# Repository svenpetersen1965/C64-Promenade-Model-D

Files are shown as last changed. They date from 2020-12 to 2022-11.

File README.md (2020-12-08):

# C64-Promenade-Model-D
This is a remake of an  EPROM programmer, originally created by Jason-Ranheim. The project was made in co-operation with <a href="http://c64os.com">C64OS/Greg</a>.

I did the layout, Greg provided the information, has built the prototye and performed the testing (many but not all EPROM Types, that are listed in the <a href="https://github.com/svenpetersen1965/C64-Promenade-Model-D/blob/main/Software/PromenadeC1Man.pdf">manual</a>. A prototype for me was provided by Greg.

So, here are the project files, which I have created, "as is".

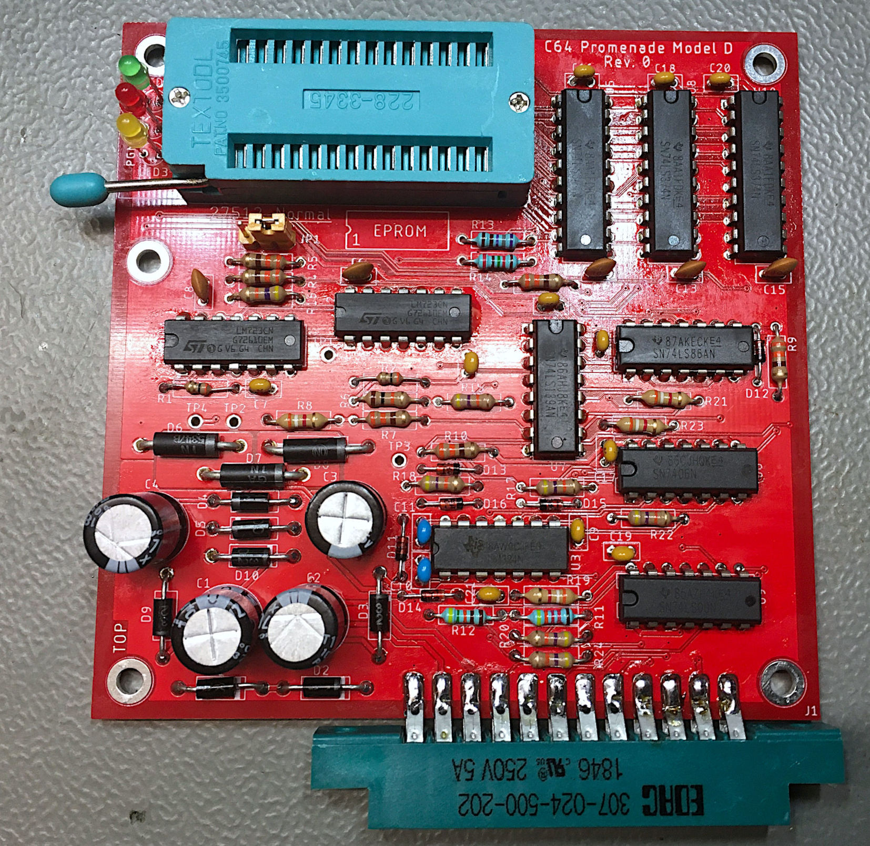
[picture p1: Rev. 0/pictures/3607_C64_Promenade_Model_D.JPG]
Promenade Model D


Since I did not test the prototype in depth, I am not able to provide support for this project.

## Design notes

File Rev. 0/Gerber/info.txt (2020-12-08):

        
       Board: C64_Promenade Model D
       Rev.:  0
  
       Files:
       ======
  
       All Gerber files are generated in extended gerber format (RS274X)
       *.TOP        : Film top copper
       *.BOT        :  -"- bottom copper
       *.STC        :  -"- top soldermask 
       *.STS        :  -"- bottom soldermask
       *.PLC        :  -"- silk screen top
       *.DK         : Drills plated Through (Excellon)
       *.NDK        : Drills not plated Through (Excellon)
       *.OUT        : Board outline

       Board Size:
       ===========
       Length     :   100.0 mm
       Width      :   100.0 mm
       Thickness  :   1.6 mm
       Material   :   FR 4
       Copper     :   35 um
       Surface    :   HASL
       
       Remarks:
       ========
       Width    >= 6 mil
       Distance >= 6 mil
       Drill    >= 0.35 mm

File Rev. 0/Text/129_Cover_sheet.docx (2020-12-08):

Project Documentation

C64 Promenade Model D

Project number: 129

Revision: 0

Date: 20.07.2019

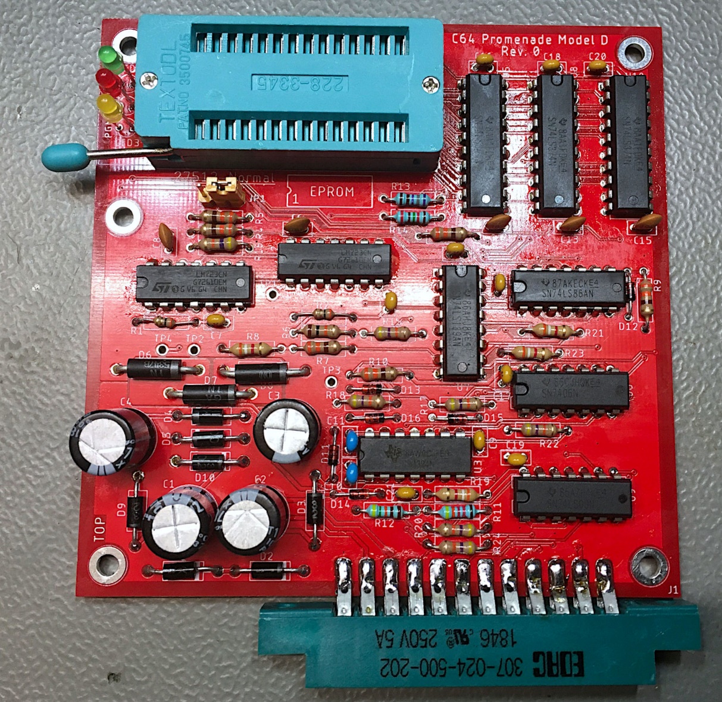
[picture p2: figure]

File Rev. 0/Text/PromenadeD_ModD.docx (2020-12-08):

C64 Promenade Model D Rev. 0

Module Description

The Promenade Model D is an EPROM programmer for the Commodore C64. The Model C is originally created by Jason-Ranheim in the 1980s. Model D is a remake of it, the layout and geometry is changed, though. The blocking of the tape port is fixed. Further, some 100n bypass capacitors were added.

This project was executed in cooperation with Greg Nacu (c64os.com). He asked me for making a layout for it. Greg has built and tested it, AFAIK with many but not all EPROM types listed.

For the documentation, please consult this website: http://c64os.com/post/promenadec1

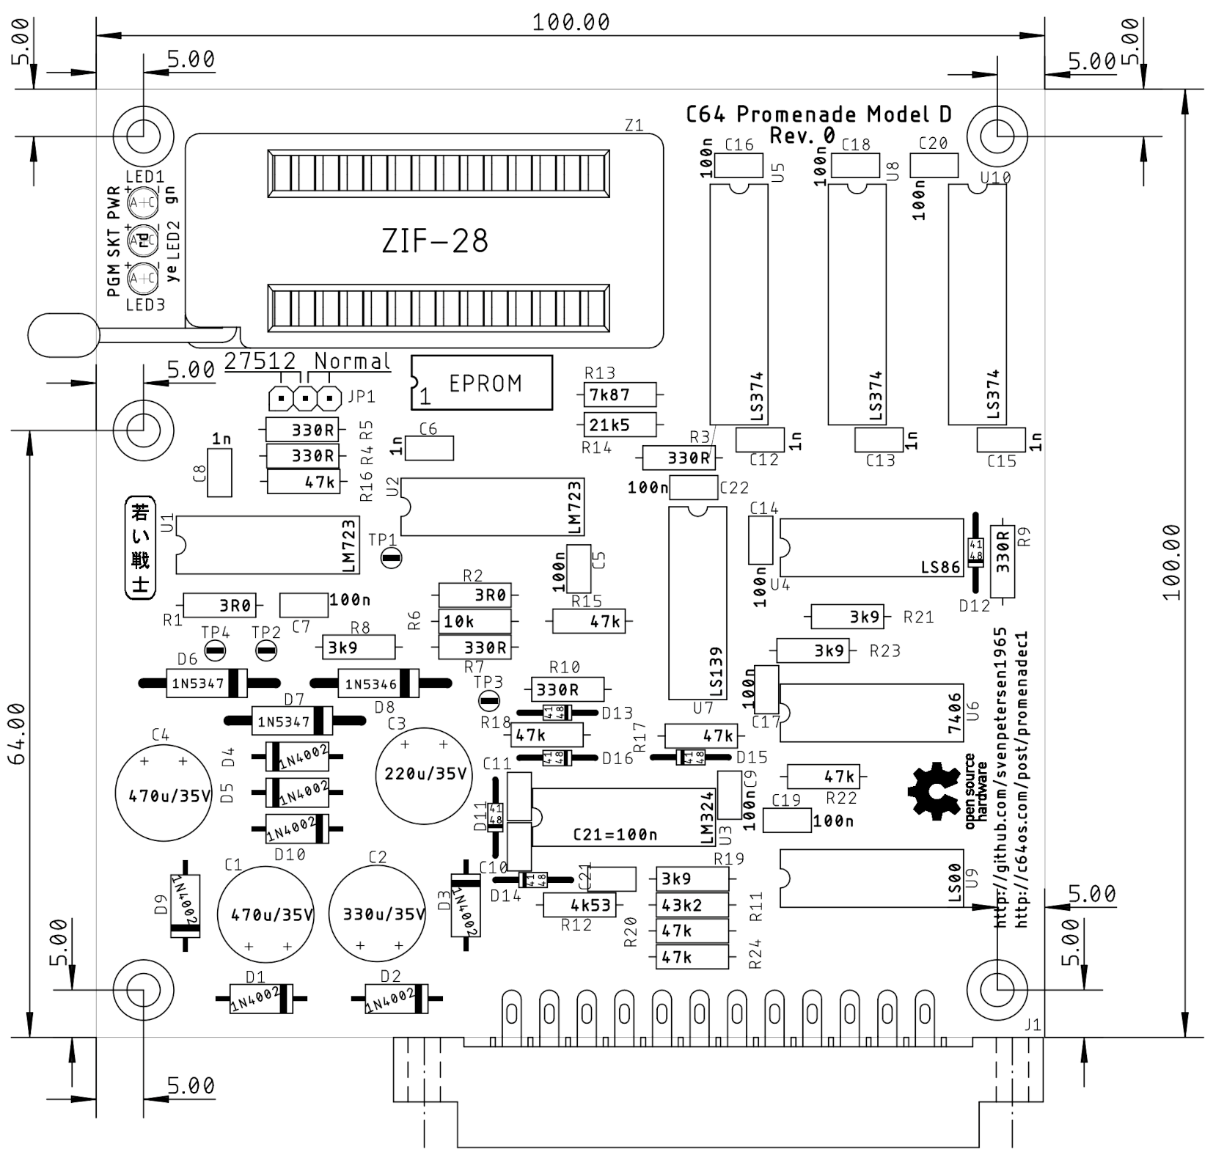
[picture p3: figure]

Figure 1: Dimensions of the Promenade Model D

This project is provided “as is”. I own a prototype, which was provided by Greg.

Dokument1 08.12.2020 10:29 Drafted by Sven Petersen Page 2 of 2 Doc.-No.: 129-6-01-00

Dokument1 08.12.2020 10:29 Drafted by Sven Petersen Page 1 of 1 Doc.-No.: 000-6-00-00

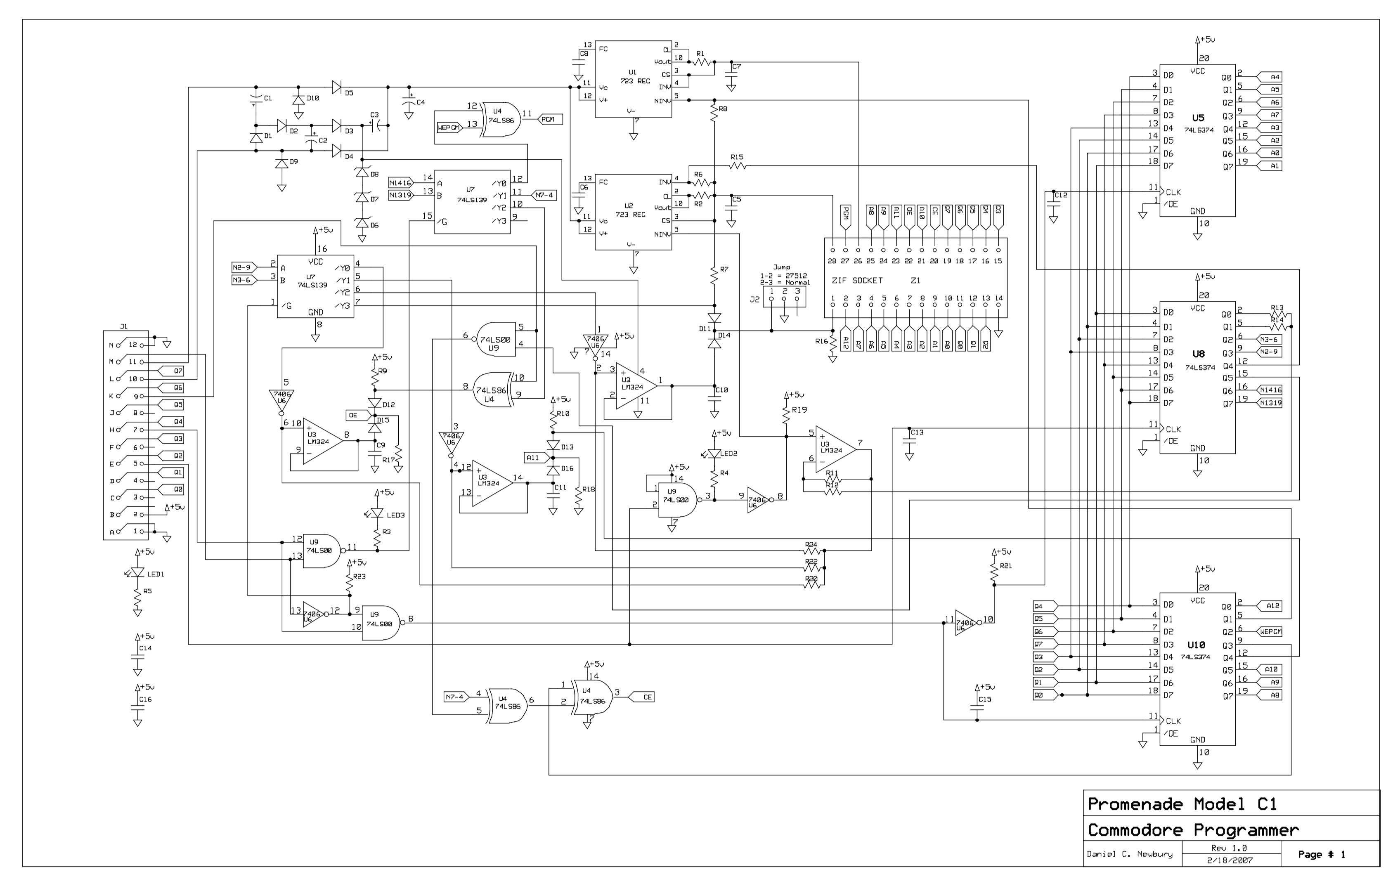
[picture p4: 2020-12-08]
Resources/C64_Promenade_ModelC1_schematics.jpg

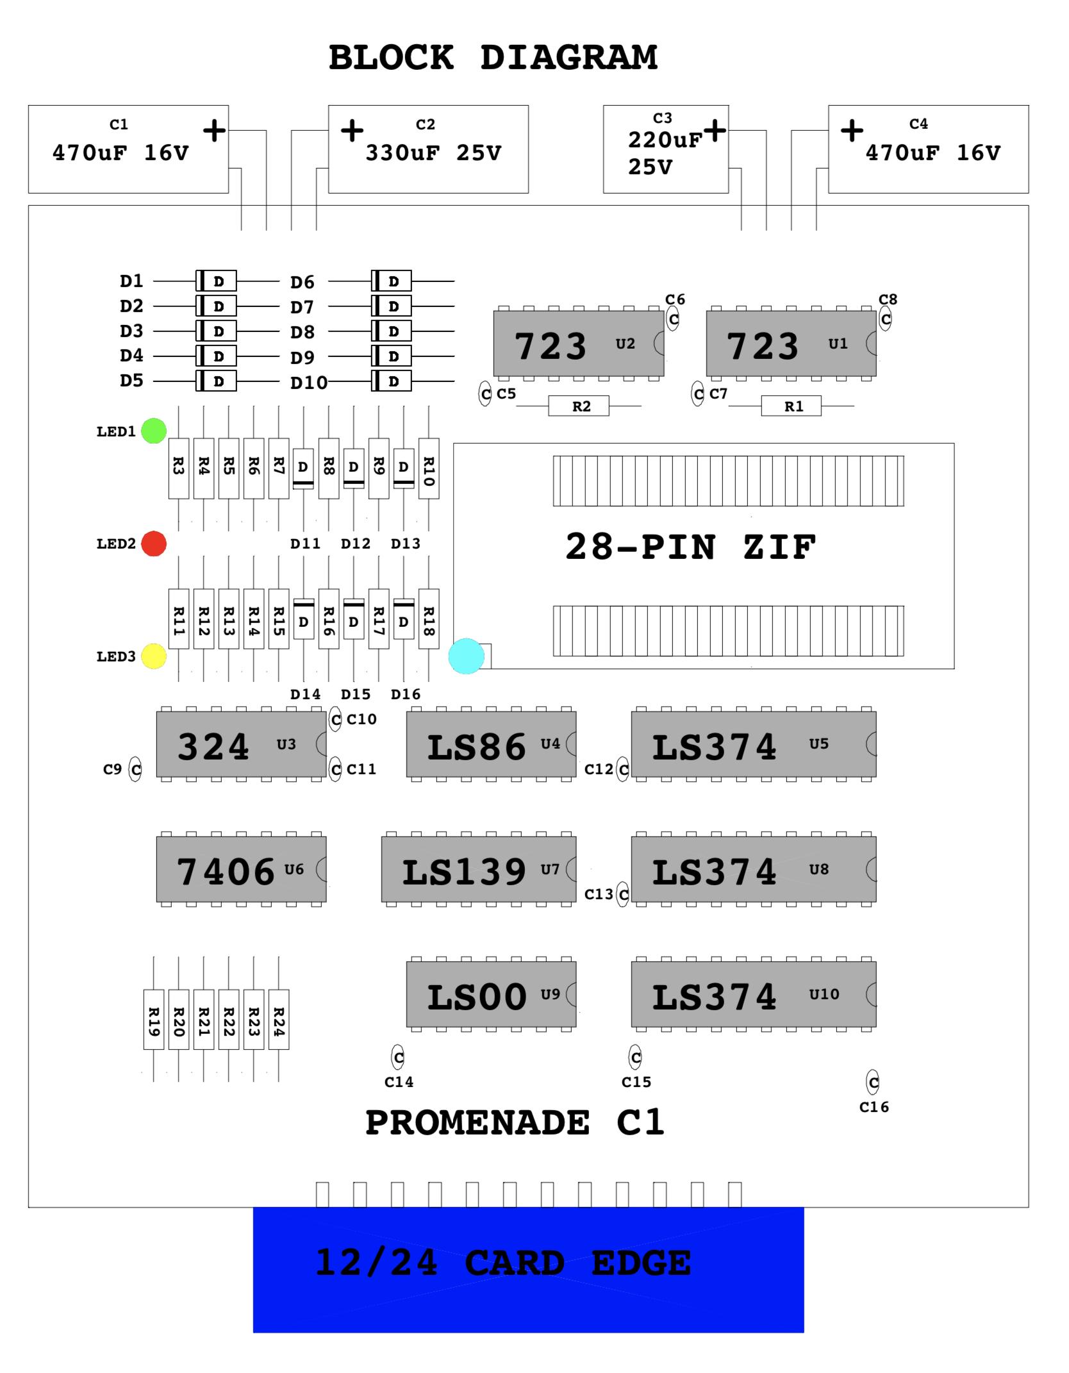
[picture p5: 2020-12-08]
Resources/C64_Promenade_ModelC1_placement.jpg

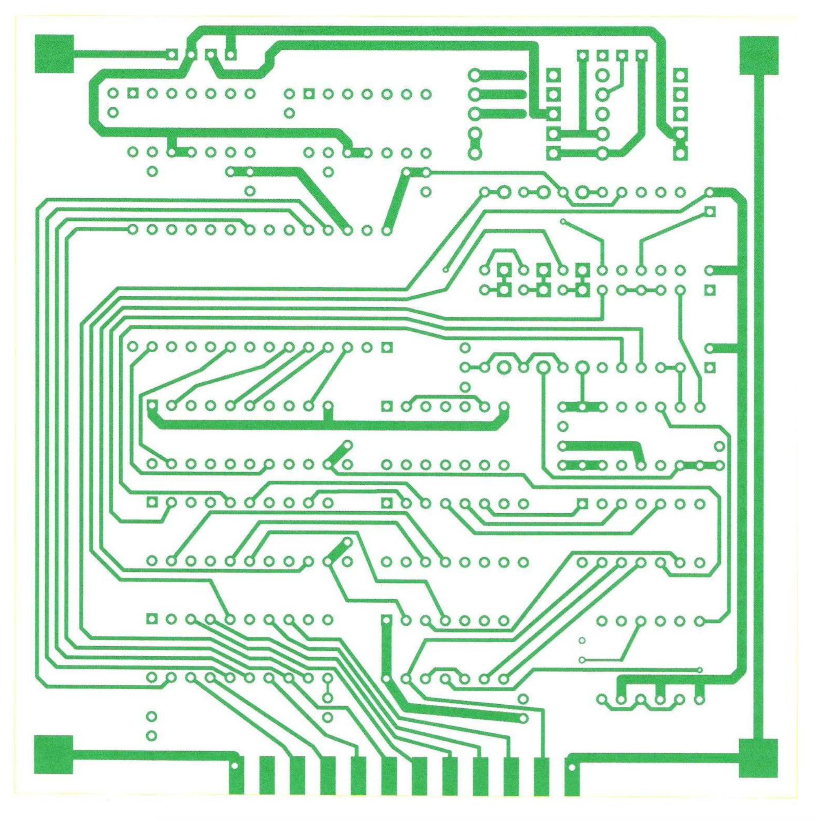
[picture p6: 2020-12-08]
Resources/C64_Promenade_ModelC1_layout bot.jpg

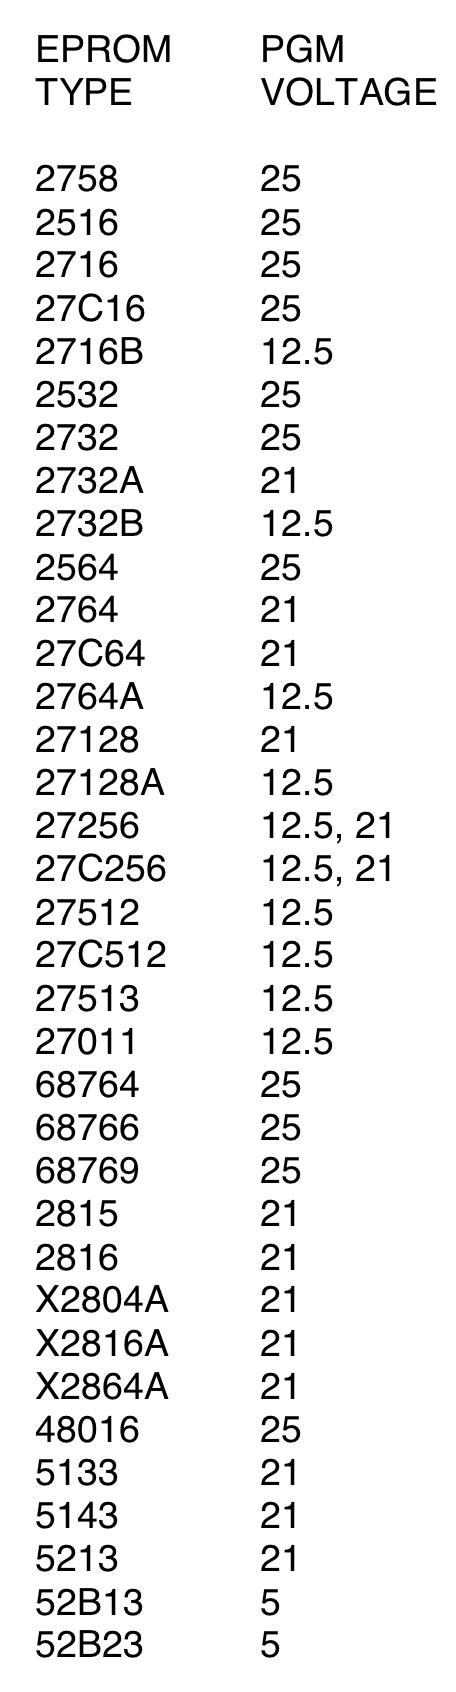
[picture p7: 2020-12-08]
Resources/C64_Promenade_ModelC1_eprom_voltage_list.jpg

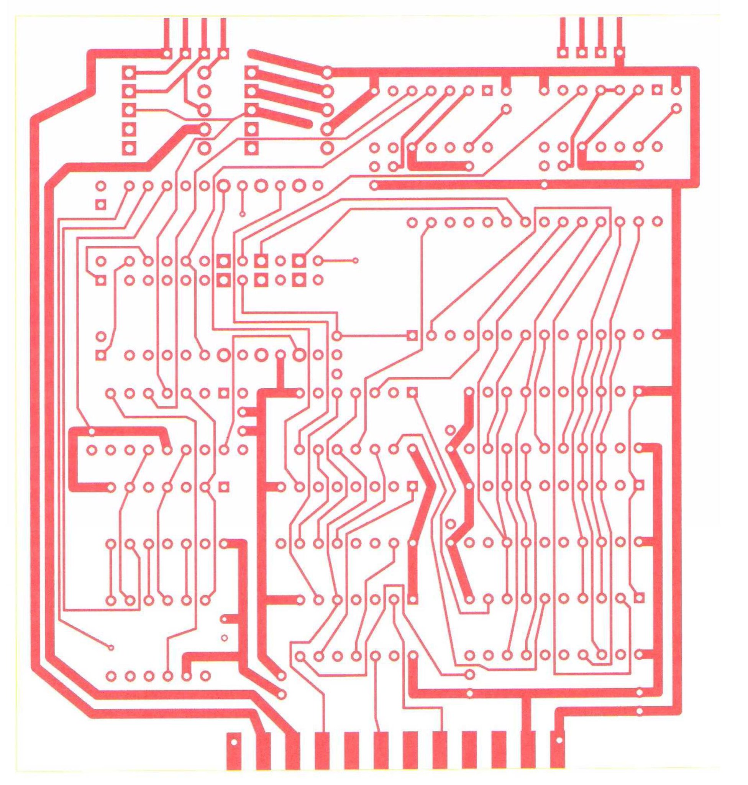
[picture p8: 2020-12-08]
Resources/C64_Promenade_ModelC1_layout top.jpg

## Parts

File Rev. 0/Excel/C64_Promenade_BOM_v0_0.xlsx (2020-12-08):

C64 Promenade Rev. 0
Bill of Material Rev. 0.0
Pos. | Qty | Value | Footprint | Ref.-No. | Comment
1 | 1 | 129-2-01-00 | 2 Layer | PCB Rev. 0 | 2 layer, Cu 35µ, HASL, 100 x 100, 1.6mm FR4
2 | 2 | 470u/35V | C10/5,0 | C1, C4 | El. cap., diam. 10mm, pitch 5,0mm, 105°C
3 | 1 | 330u/35V | C10/5,0 | C2 | El. cap., diam. 10mm, pitch 5,0mm, 105°C
4 | 1 | 220u/35V | C10/5,0 | C3 | El. cap., diam. 10mm, pitch 5,0mm, 105°C
5 | 13 | 100n | C-2,5 | C5, C7, C9, C10, C11, C14, C16, C17, C18, C19, C20, C21, C22 | cer. cap, 2.5mm pitch
6 | 5 | 1n | C-2,5 | C6, C8, C12, C13, C15 | cer. cap, 2.5mm pitch
7 | 7 | 1N4002 | DO-41 | D1, D2, D3, D4, D5, D9, D10
8 | 6 | 1N4148 | DO-35 | D11, D12, D13, D14, D15, D16
9 | 2 | 1N5347BG | 017AA | D6, D7 | On-Semi, Zener 10V, 5W
10 | 1 | 1N5346BG | 017AA | D8 | On-Semi, Zener 9.1V, 5W
11 | 1 | 2x12, 3,96mm | USERPORT | J1 | Edge connector for C64 User Port
12 | 1 | pinheader 3p, 2.54mm | 1X03 | JP1 | plus 1 jumper
13 | 1 | 3mm/gn | 3MM | LED1 | led 3mm, green
14 | 1 | 3mm/rd | 3mm | LED2 | led 3mm, red
15 | 1 | 3mm/ye | 3MM | LED3 | led 3mm, yellow
16 | 2 | 3R0 | R-10 | R1, R2 | Resistor 1/4W, 5%
17 | 1 | 43k2 | R-10 | R11 | Resistor 1/4W, 1%
18 | 1 | 4k53 | R-10 | R12 | Resistor 1/4W, 1%
19 | 1 | 7k87 | R-10 | R13 | Resistor 1/4W, 1%
20 | 1 | 21k5 | R-10 | R14 | Resistor 1/4W, 1%
21 | 7 | 47k | R-10 | R15, R16, R17, R18, R20, R22, R24 | Resistor 1/4W, 5%
22 | 6 | 330R | R-10 | R3, R4, R5, R7, R9, R10 | Resistor 1/4W, 5%
23 | 1 | 10k | R-10 | R6 | Resistor 1/4W, 5%
24 | 4 | 3k9 | R-10 | R8, R19, R21, R23 | Resistor 1/4W, 5%
25 | 2 | LM723 | DIL-14 | U1, U2
26 | 1 | LM324N | DIL-14 | U3
27 | 1 | SN74LS86 | DIL-14 | U4
28 | 3 | SN74LS374 | DIL-20 | U5, U8, U10
29 | 1 | SN7406N | DIL-14 | U6
30 | 1 | SN74LS139 | DIL-16 | U7
31 | 1 | SN74LS00 | DIL-14 | U9
32 | 1 | ZIF-28 | ZIF28 | Z1 | ZIF socket, 28p

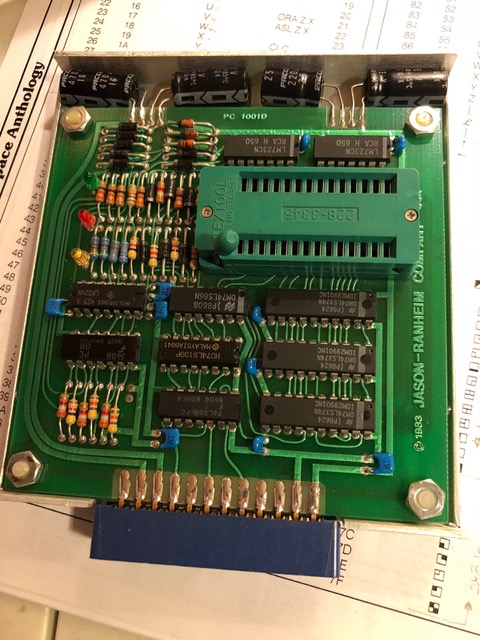
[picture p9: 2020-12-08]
Resources/C64_Promenade_ModelC1_promenade-purchase-inside.jpg

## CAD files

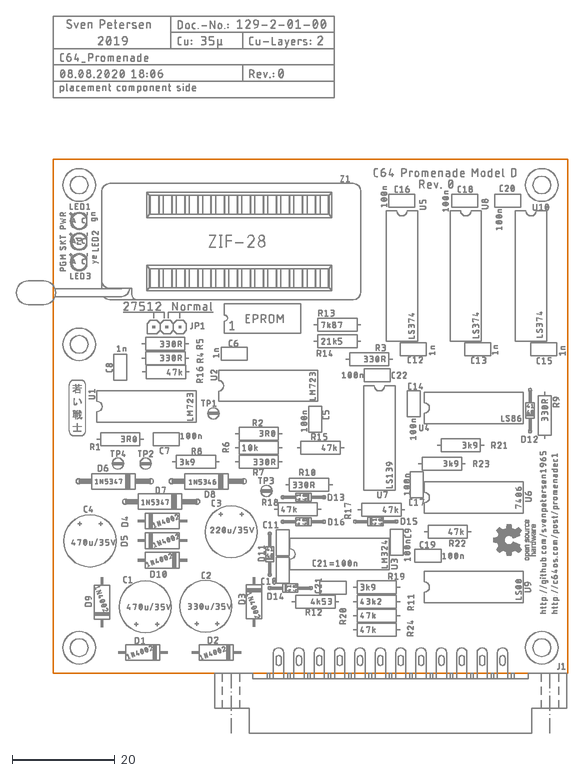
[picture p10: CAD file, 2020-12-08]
Rev. 0/dxf/C64_Promenade.dxf
107.2 x 139.5

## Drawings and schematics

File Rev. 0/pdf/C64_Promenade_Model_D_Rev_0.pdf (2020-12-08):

# Project Documentation

## C64 Promenade Model D

## Project number: 129

## Revision: 0

## Date: 20.07.2019

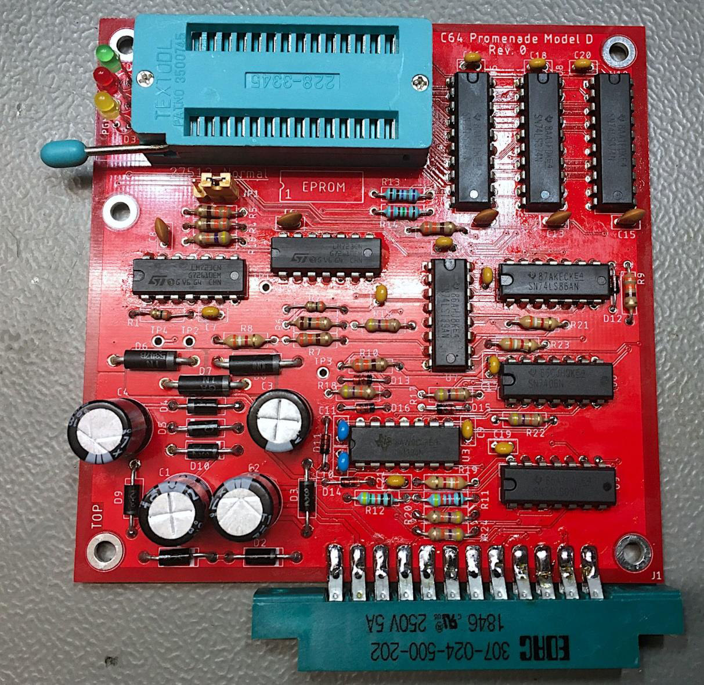
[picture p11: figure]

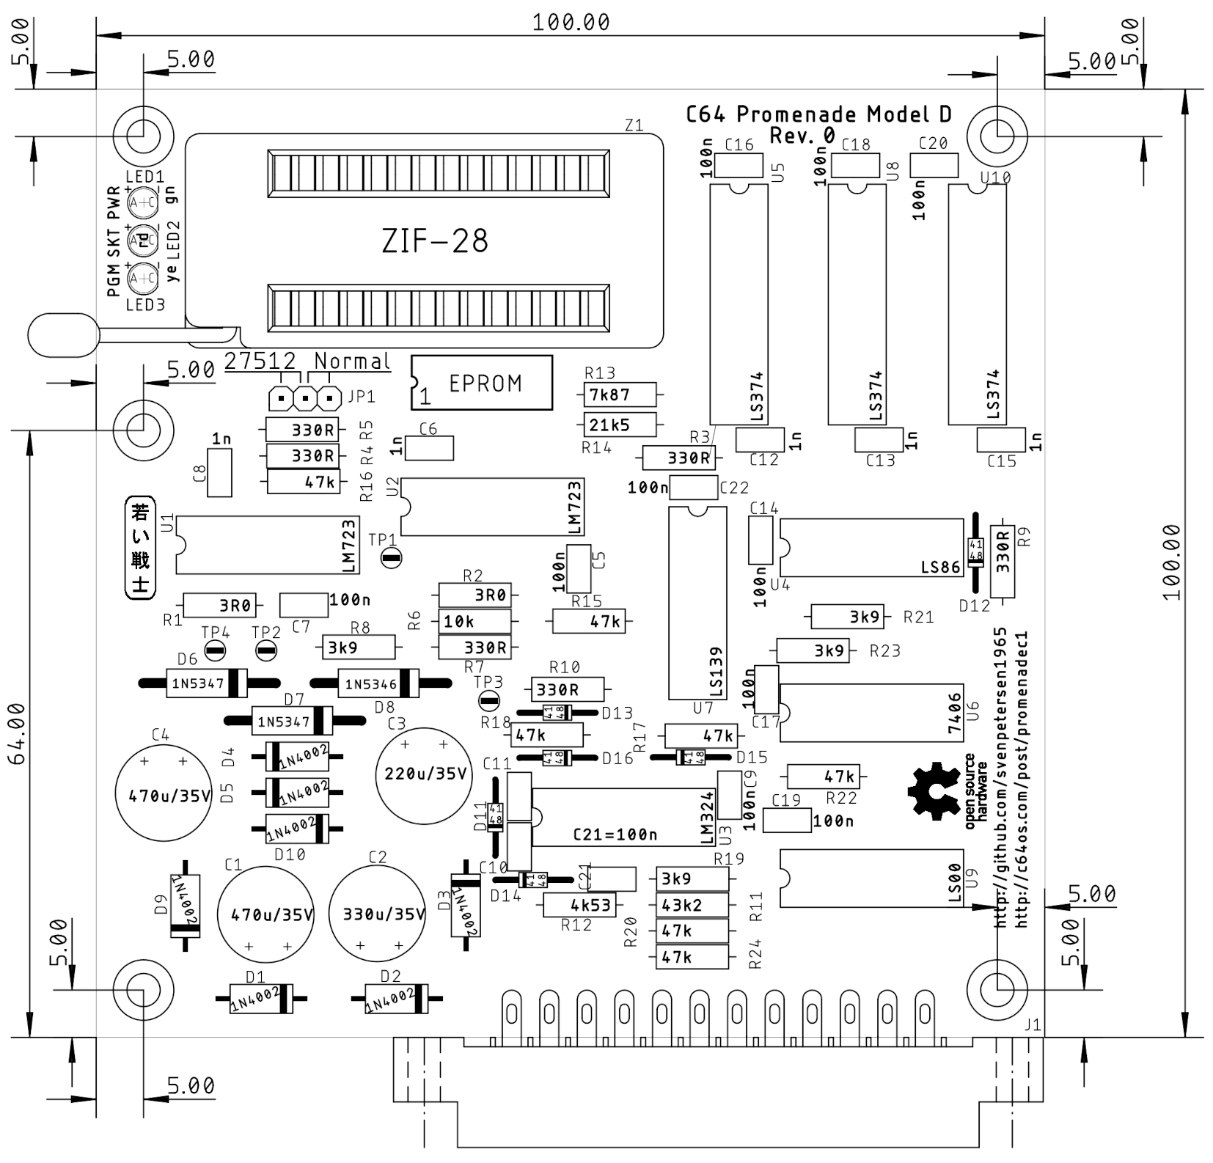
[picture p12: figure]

PromenadeD_ModD.docx | | 08.12.2020 10:29
Drafted by Sven Petersen | Page 1 of 1 | Doc.-No.: 129-6-01-00

### C64 Promenade Model D Rev. 0

### Module Description

The Promenade Model D is an EPROM programmer for the Commodore C64. The Model C is originally created by Jason-Ranheim in the 1980s. Model D is a remake of it, the layout and geometry is changed, though. The blocking of the tape port is fixed. Further, some 100n bypass capacitors were added.

This project was executed in cooperation with Greg Nacu (c64os.com). He asked me for making a layout for it. Greg has built and tested it, AFAIK with many but not all EPROM types listed.

For the documentation, please consult this website: http://c64os.com/post/promenadec1

Figure 1: Dimensions of the Promenade Model D
This project is provided “as is”. I own a prototype, which was provided by Greg.

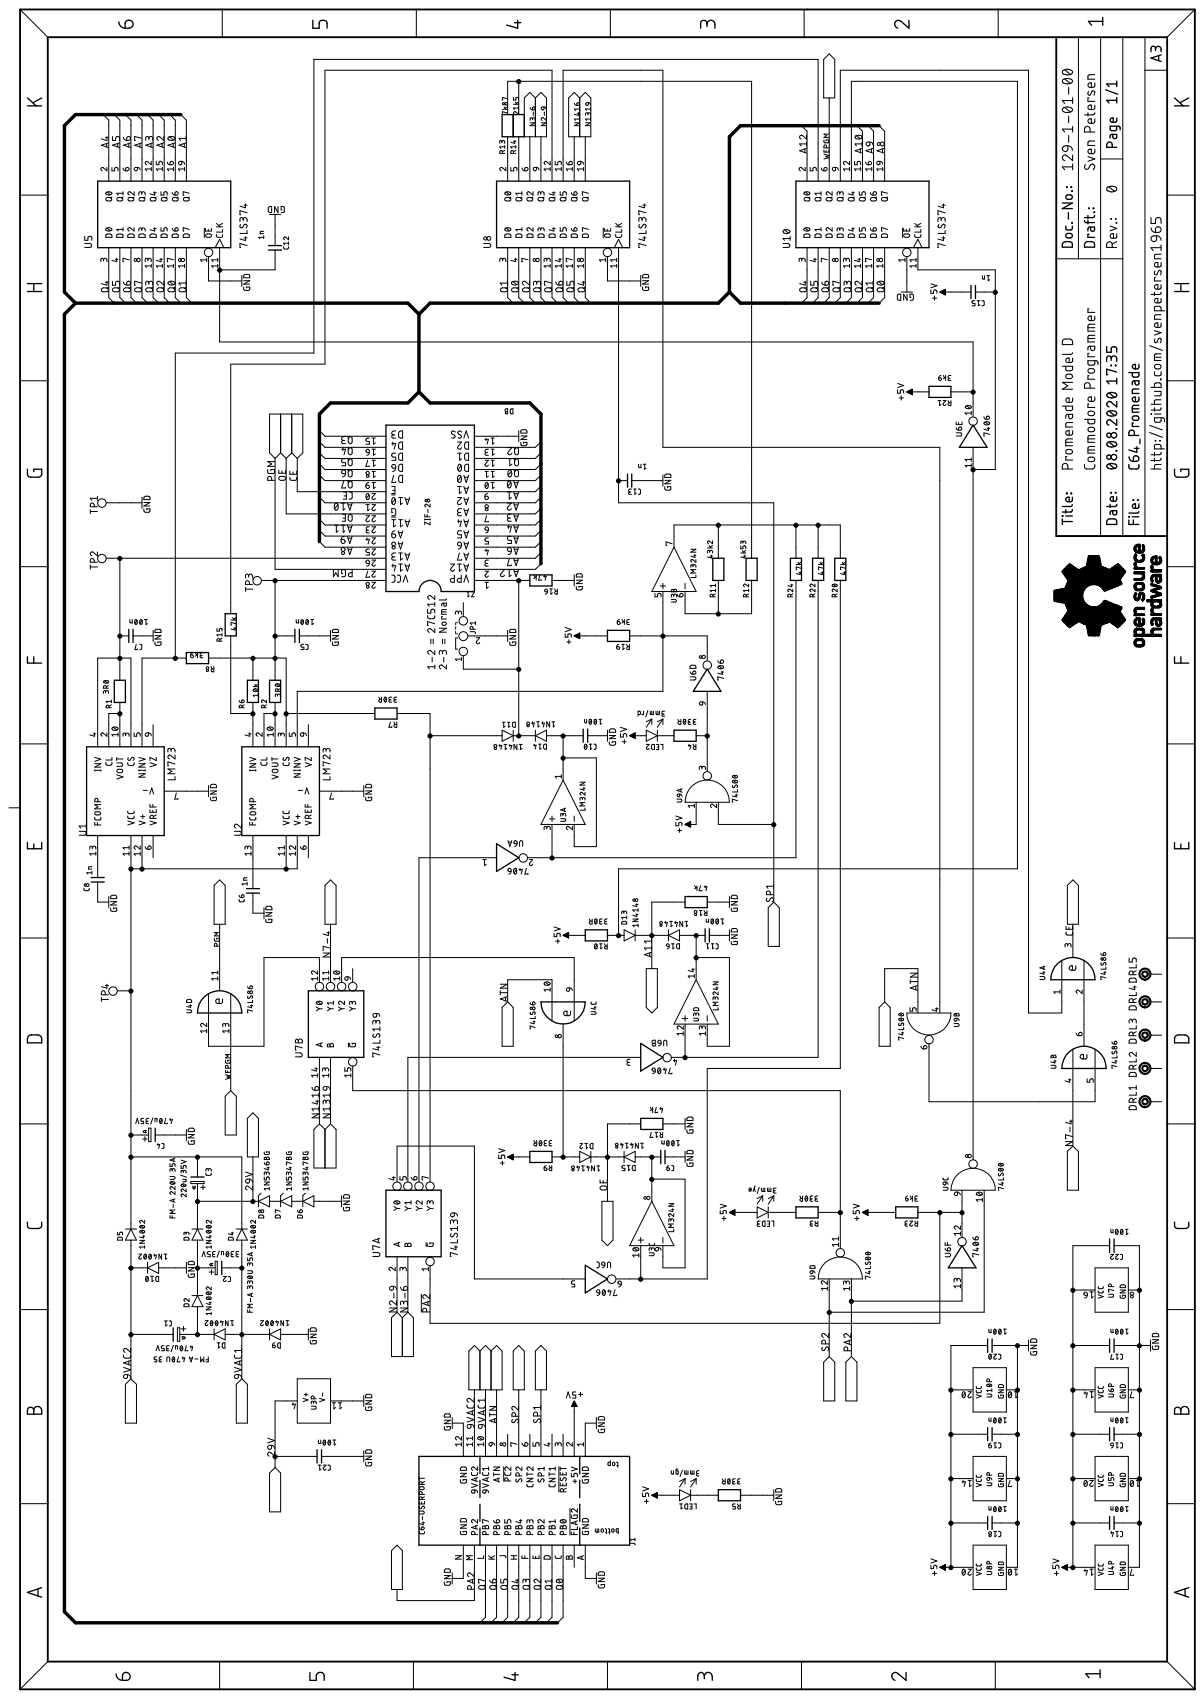
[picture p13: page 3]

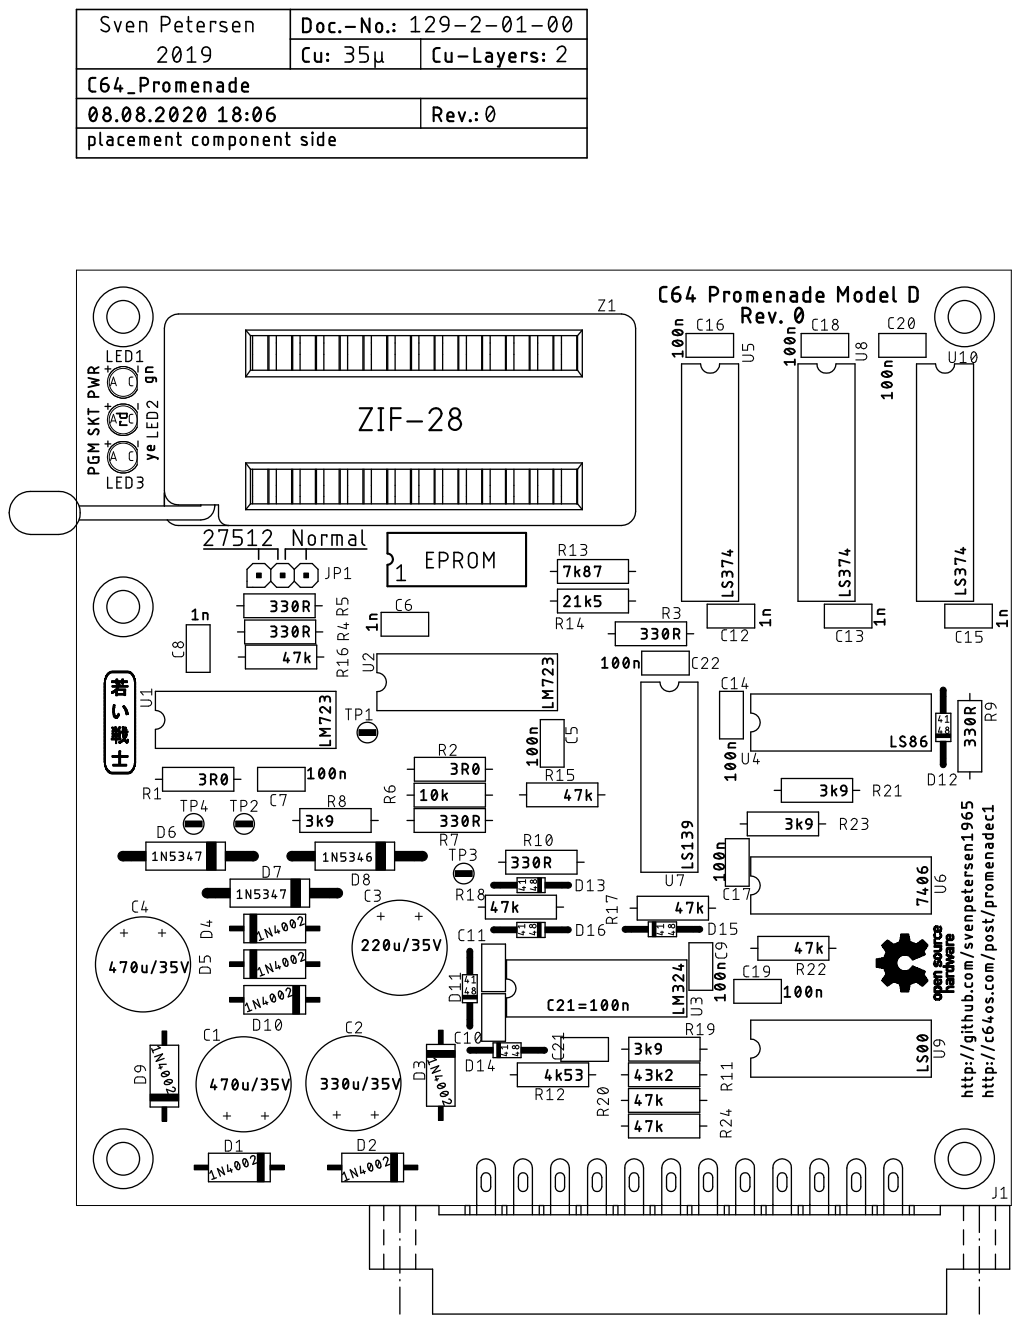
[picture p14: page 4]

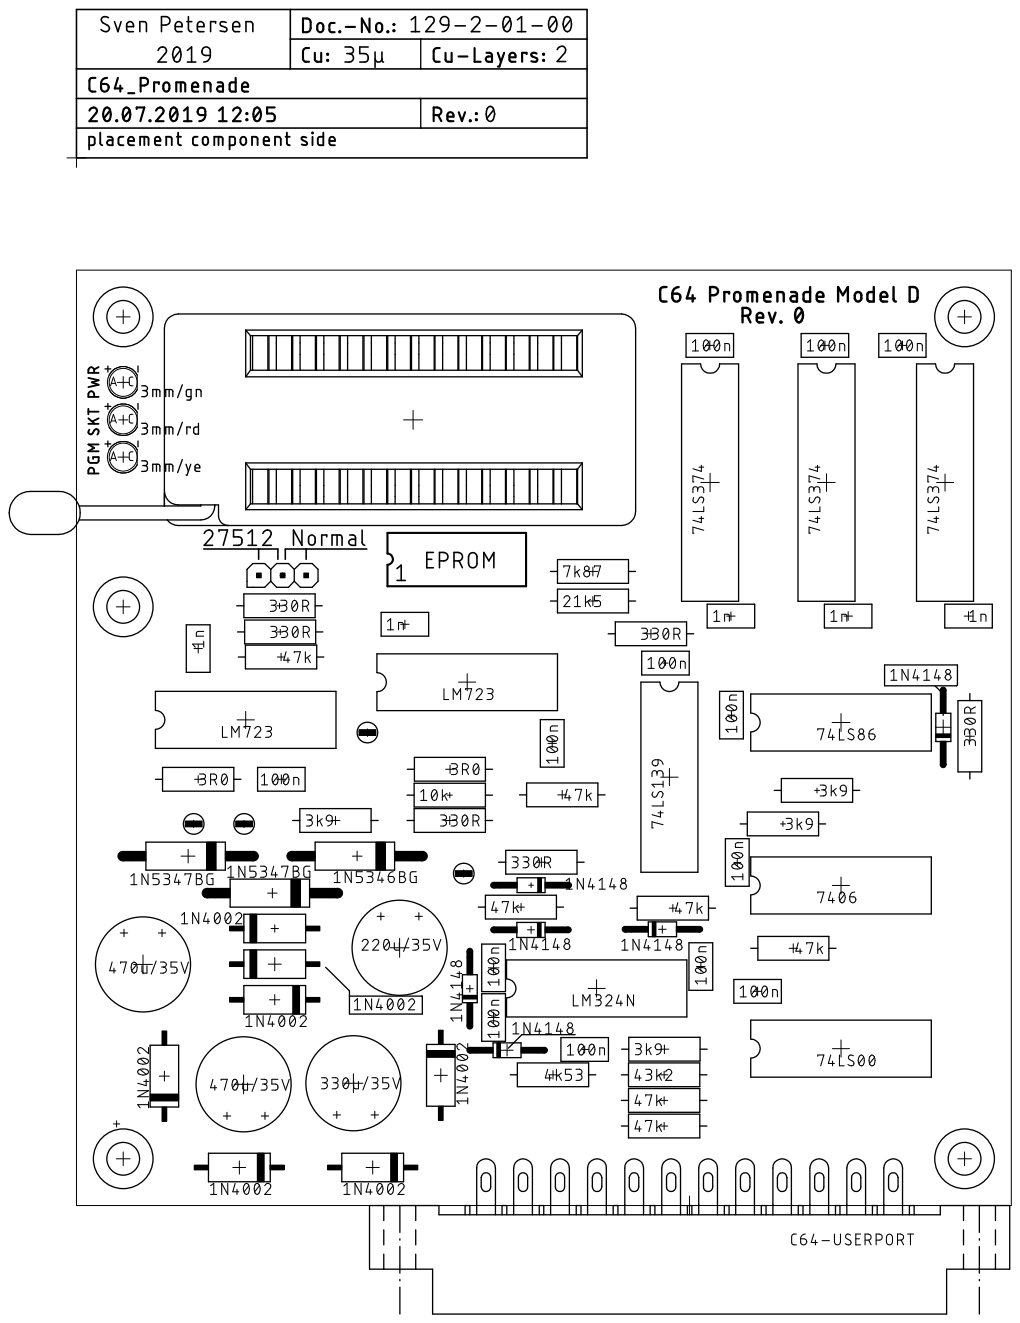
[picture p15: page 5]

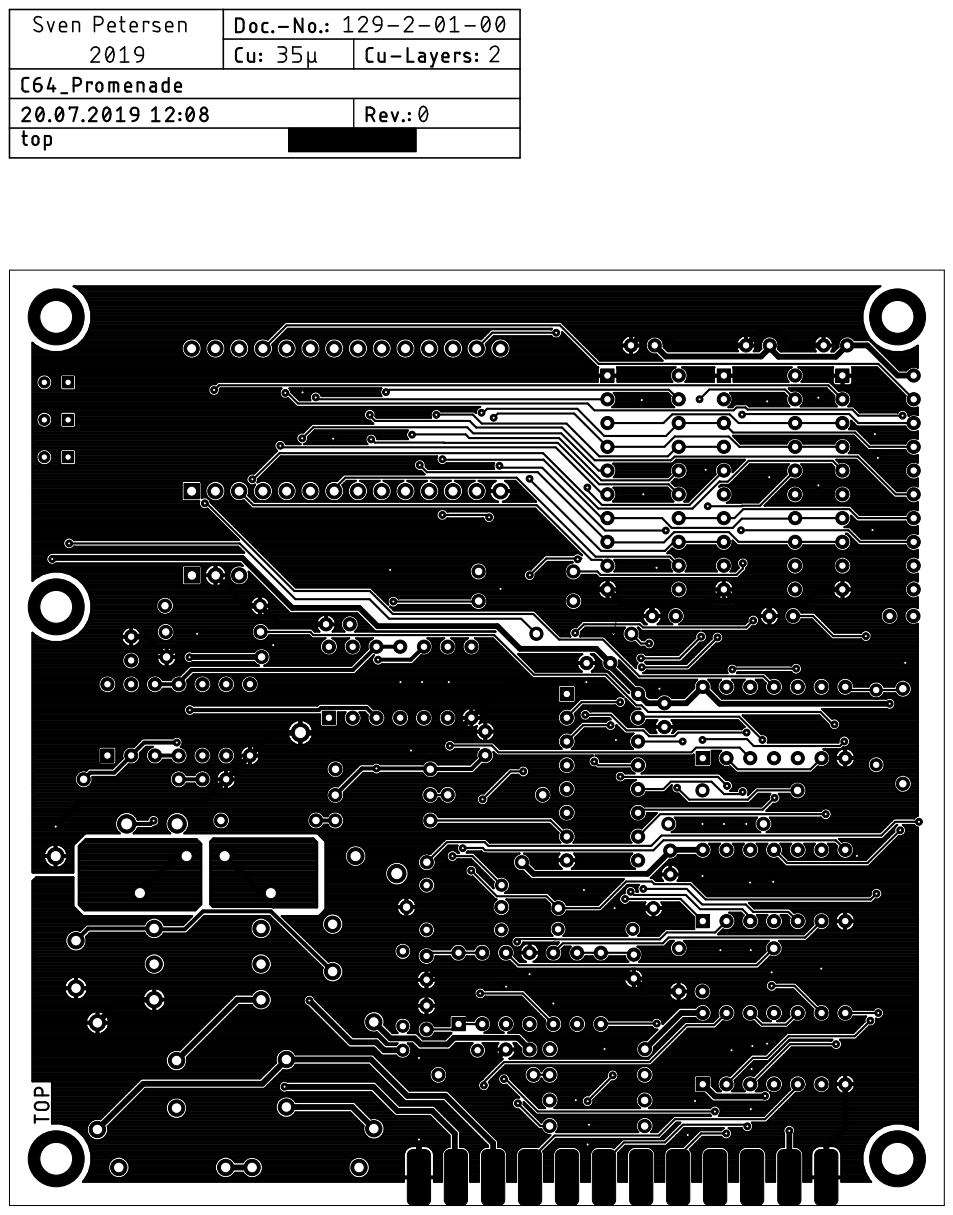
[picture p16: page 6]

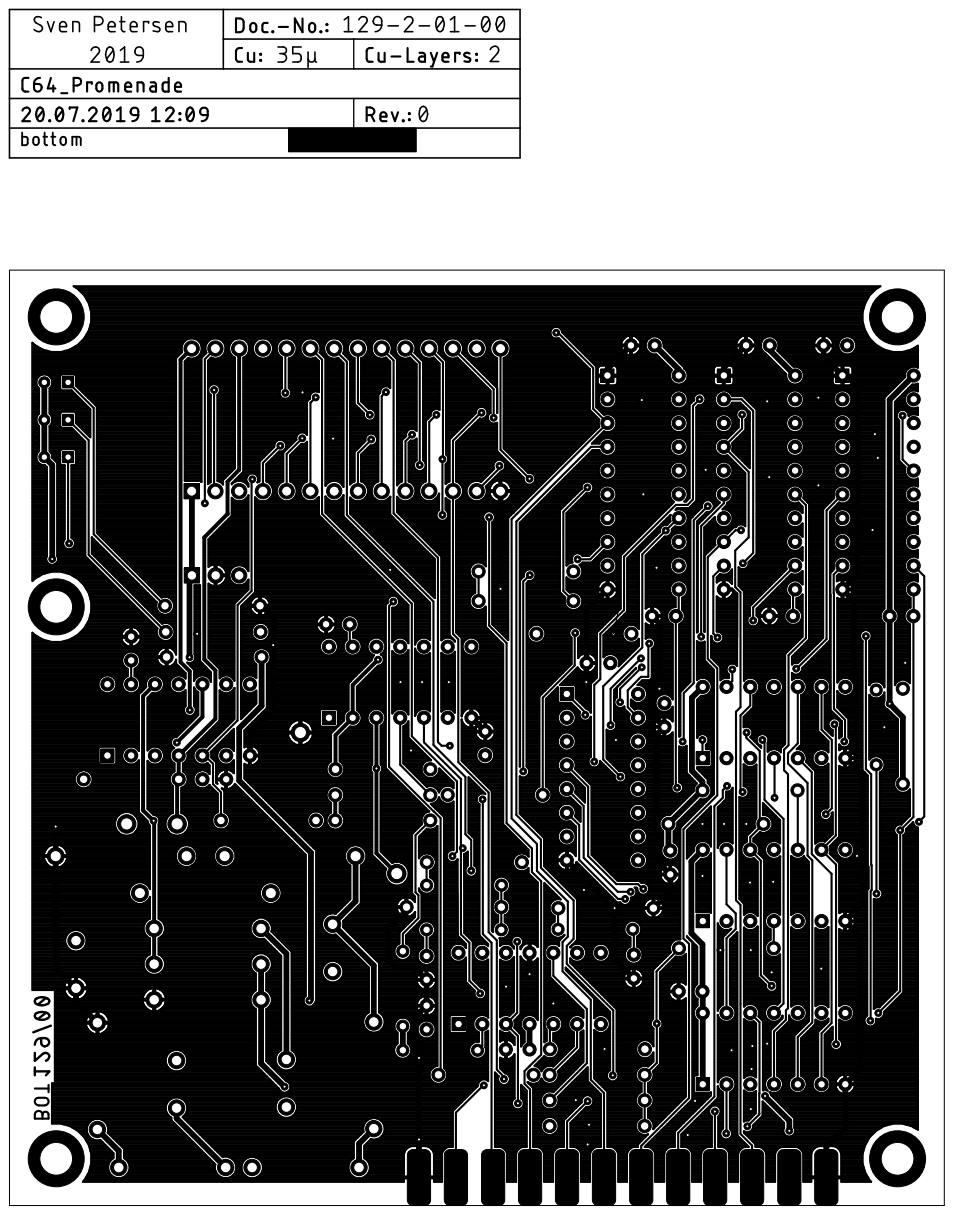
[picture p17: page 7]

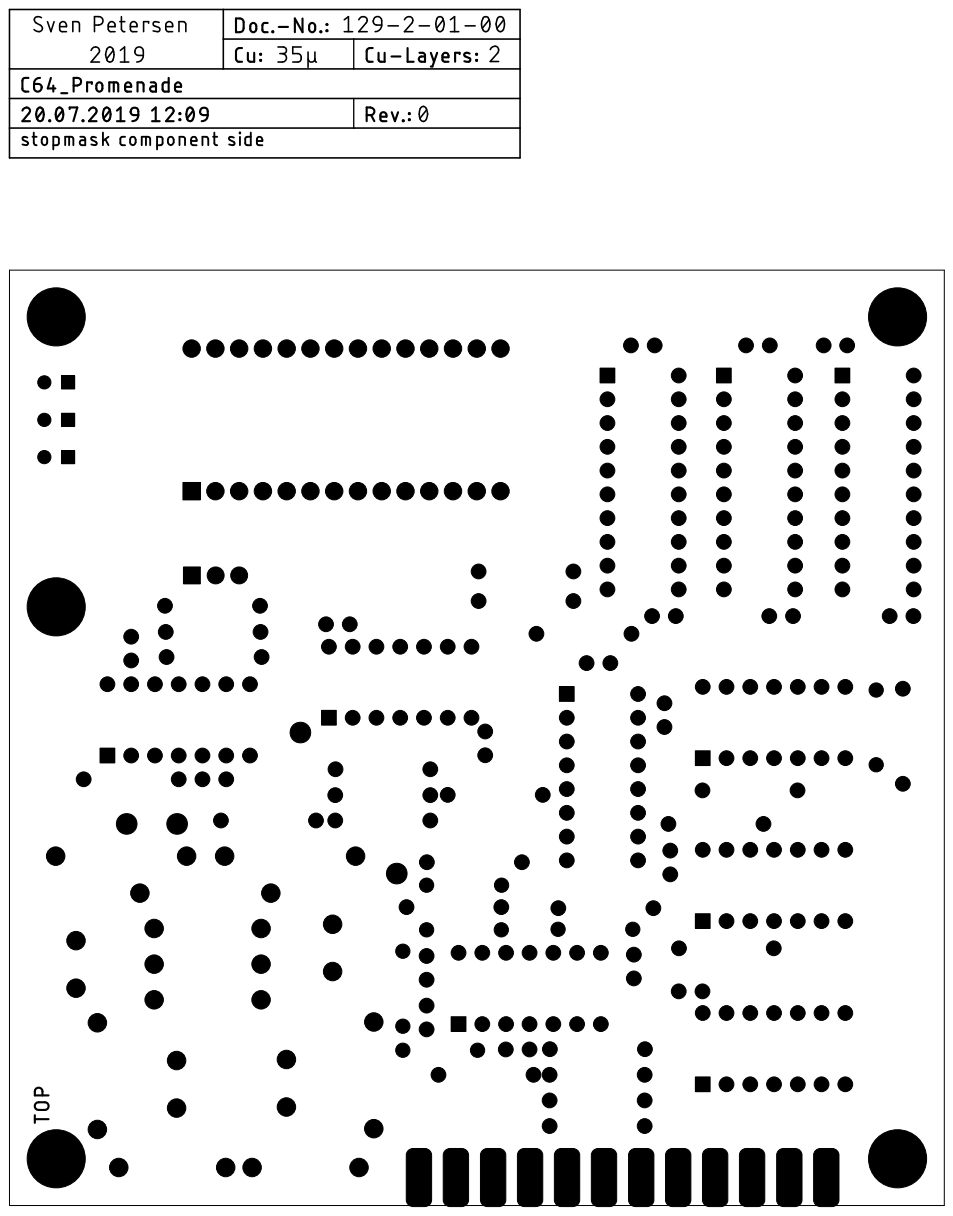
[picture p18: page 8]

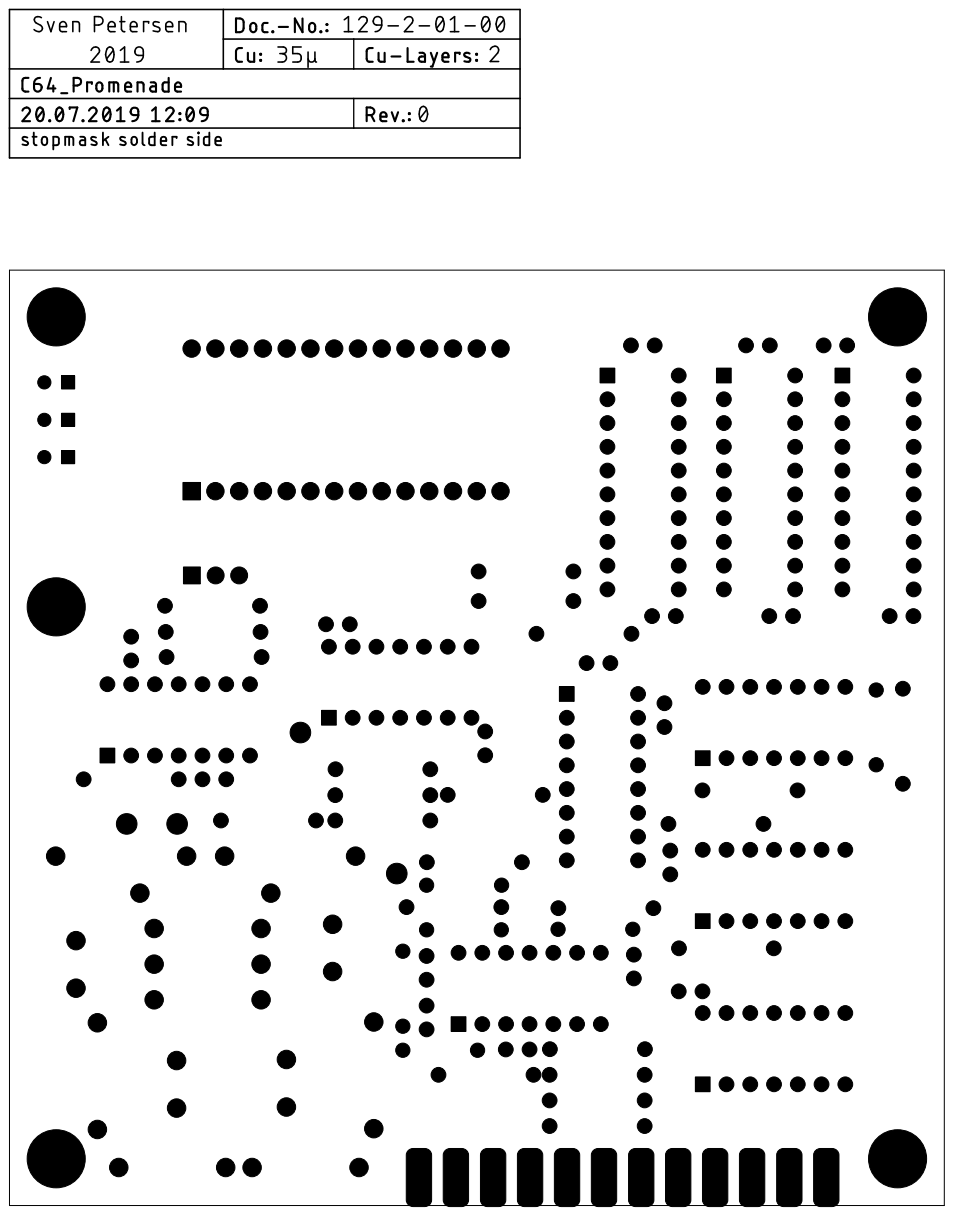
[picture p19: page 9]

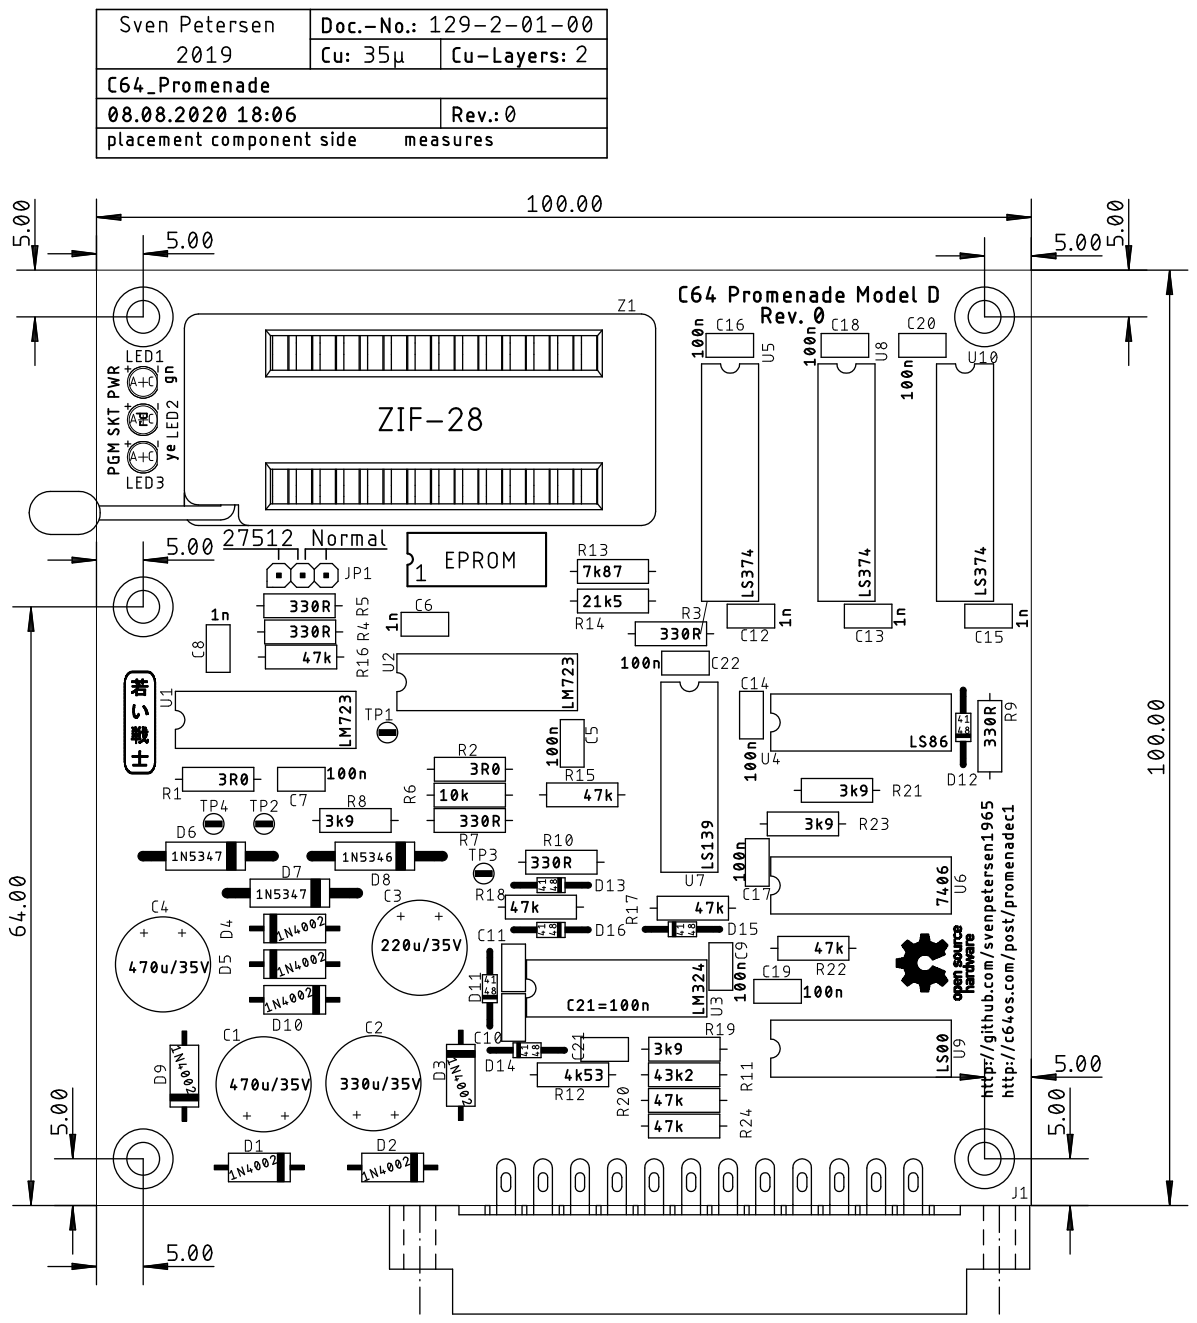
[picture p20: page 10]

Pos. Qty Value Footprint Ref.-No. Comment

1 1 129-2-01-00 2 Layer PCB Rev. 0 2 layer, Cu 35µ, HASL, 100 x 100, 1.6mm FR4
2 2 470u/35V C10/5,0 C1, C4 El. cap., diam. 10mm, pitch 5,0mm, 105°C

3 1 330u/35V C10/5,0 C2 El. cap., diam. 10mm, pitch 5,0mm, 105°C

4 1 220u/35V C10/5,0 C3 El. cap., diam. 10mm, pitch 5,0mm, 105°C

5 13 100n C-2,5 C5, C7, C9, C10, C11, C14,
C16, C17, C18, C19, C20,

C21, C22

cer. cap, 2.5mm pitch

6 5 1n C-2,5 C6, C8, C12, C13, C15 cer. cap, 2.5mm pitch

7 7 1N4002 DO-41 D1, D2, D3, D4, D5, D9, D10
8 6 1N4148 DO-35 D11, D12, D13, D14, D15,

D16

9 2 1N5347BG 017AA D6, D7 On-Semi, Zener 10V, 5W

10 1 1N5346BG 017AA D8 On-Semi, Zener 9.1V, 5W

11 1 2x12, 3,96mm USERPORT J1 Edge connector for C64 User Port

12 1 pinheader 3p, 2.54mm 1X03 JP1 plus 1 jumper

13 1 3mm/gn 3MM LED1 led 3mm, green
14 1 3mm/rd 3mm LED2 led 3mm, red

15 1 3mm/ye 3MM LED3 led 3mm, yellow

16 2 3R0 R-10 R1, R2 Resistor 1/4W, 5%
17 1 43k2 R-10 R11 Resistor 1/4W, 1%

18 1 4k53 R-10 R12 Resistor 1/4W, 1%

19 1 7k87 R-10 R13 Resistor 1/4W, 1%

20 1 21k5 R-10 R14 Resistor 1/4W, 1%

21 7 47k R-10 R15, R16, R17, R18, R20, R22,

R24

Resistor 1/4W, 5%
22 6 330R R-10 R3, R4, R5, R7, R9, R10 Resistor 1/4W, 5%

23 1 10k R-10 R6 Resistor 1/4W, 5%
24 4 3k9 R-10 R8, R19, R21, R23 Resistor 1/4W, 5%

25 2 LM723 DIL-14 U1, U2

## C64 Promenade Rev. 0

## Bill of Material Rev. 0.0

C64_Promenade_BOM_v0_0.xlsx

Drafted by Sven Petersen Page 1 of 2

20.07.2019 12:24
Doc.No.: 129-5-01-00.0

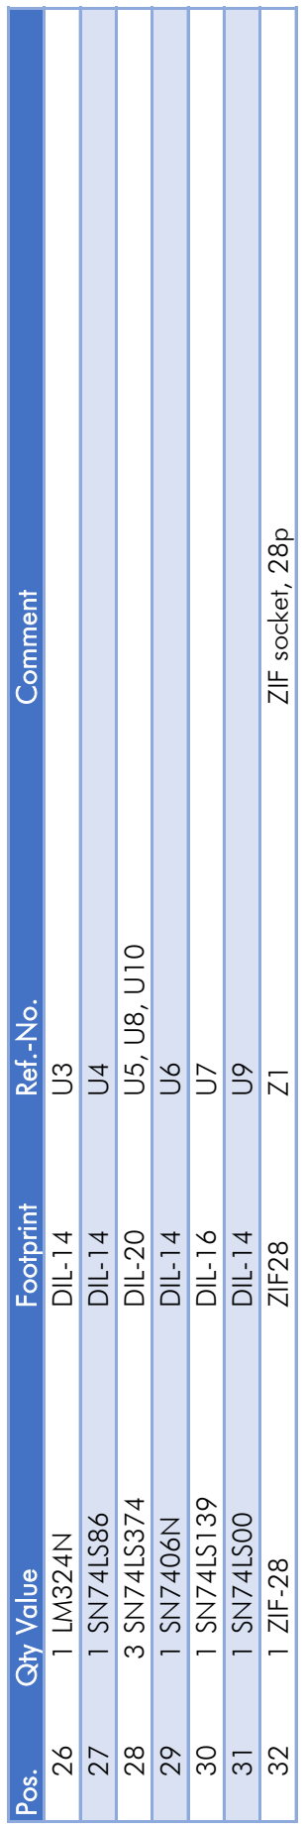
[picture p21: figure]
26 1 LM324N DIL-14 U3; 27 1 SN74LS86 DIL-14 U4; 28 3 SN74LS374 DIL-20 U5, U8, U10; 29 1 SN7406N DIL-14 U6; 30 1 SN74LS139 DIL-16 U7; 31 1 SN74LS00 DIL-14 U9; 32 1 ZIF-28 ZIF28 Z1 ZIF socket, 28p

Pos. Qty Value Footprint Ref.-No. Comment

## C64 Promenade Rev. 0

## Bill of Material Rev. 0.0

C64_Promenade_BOM_v0_0.xlsx

Drafted by Sven Petersen Page 2 of 2

20.07.2019 12:24
Doc.No.: 129-5-01-00.0

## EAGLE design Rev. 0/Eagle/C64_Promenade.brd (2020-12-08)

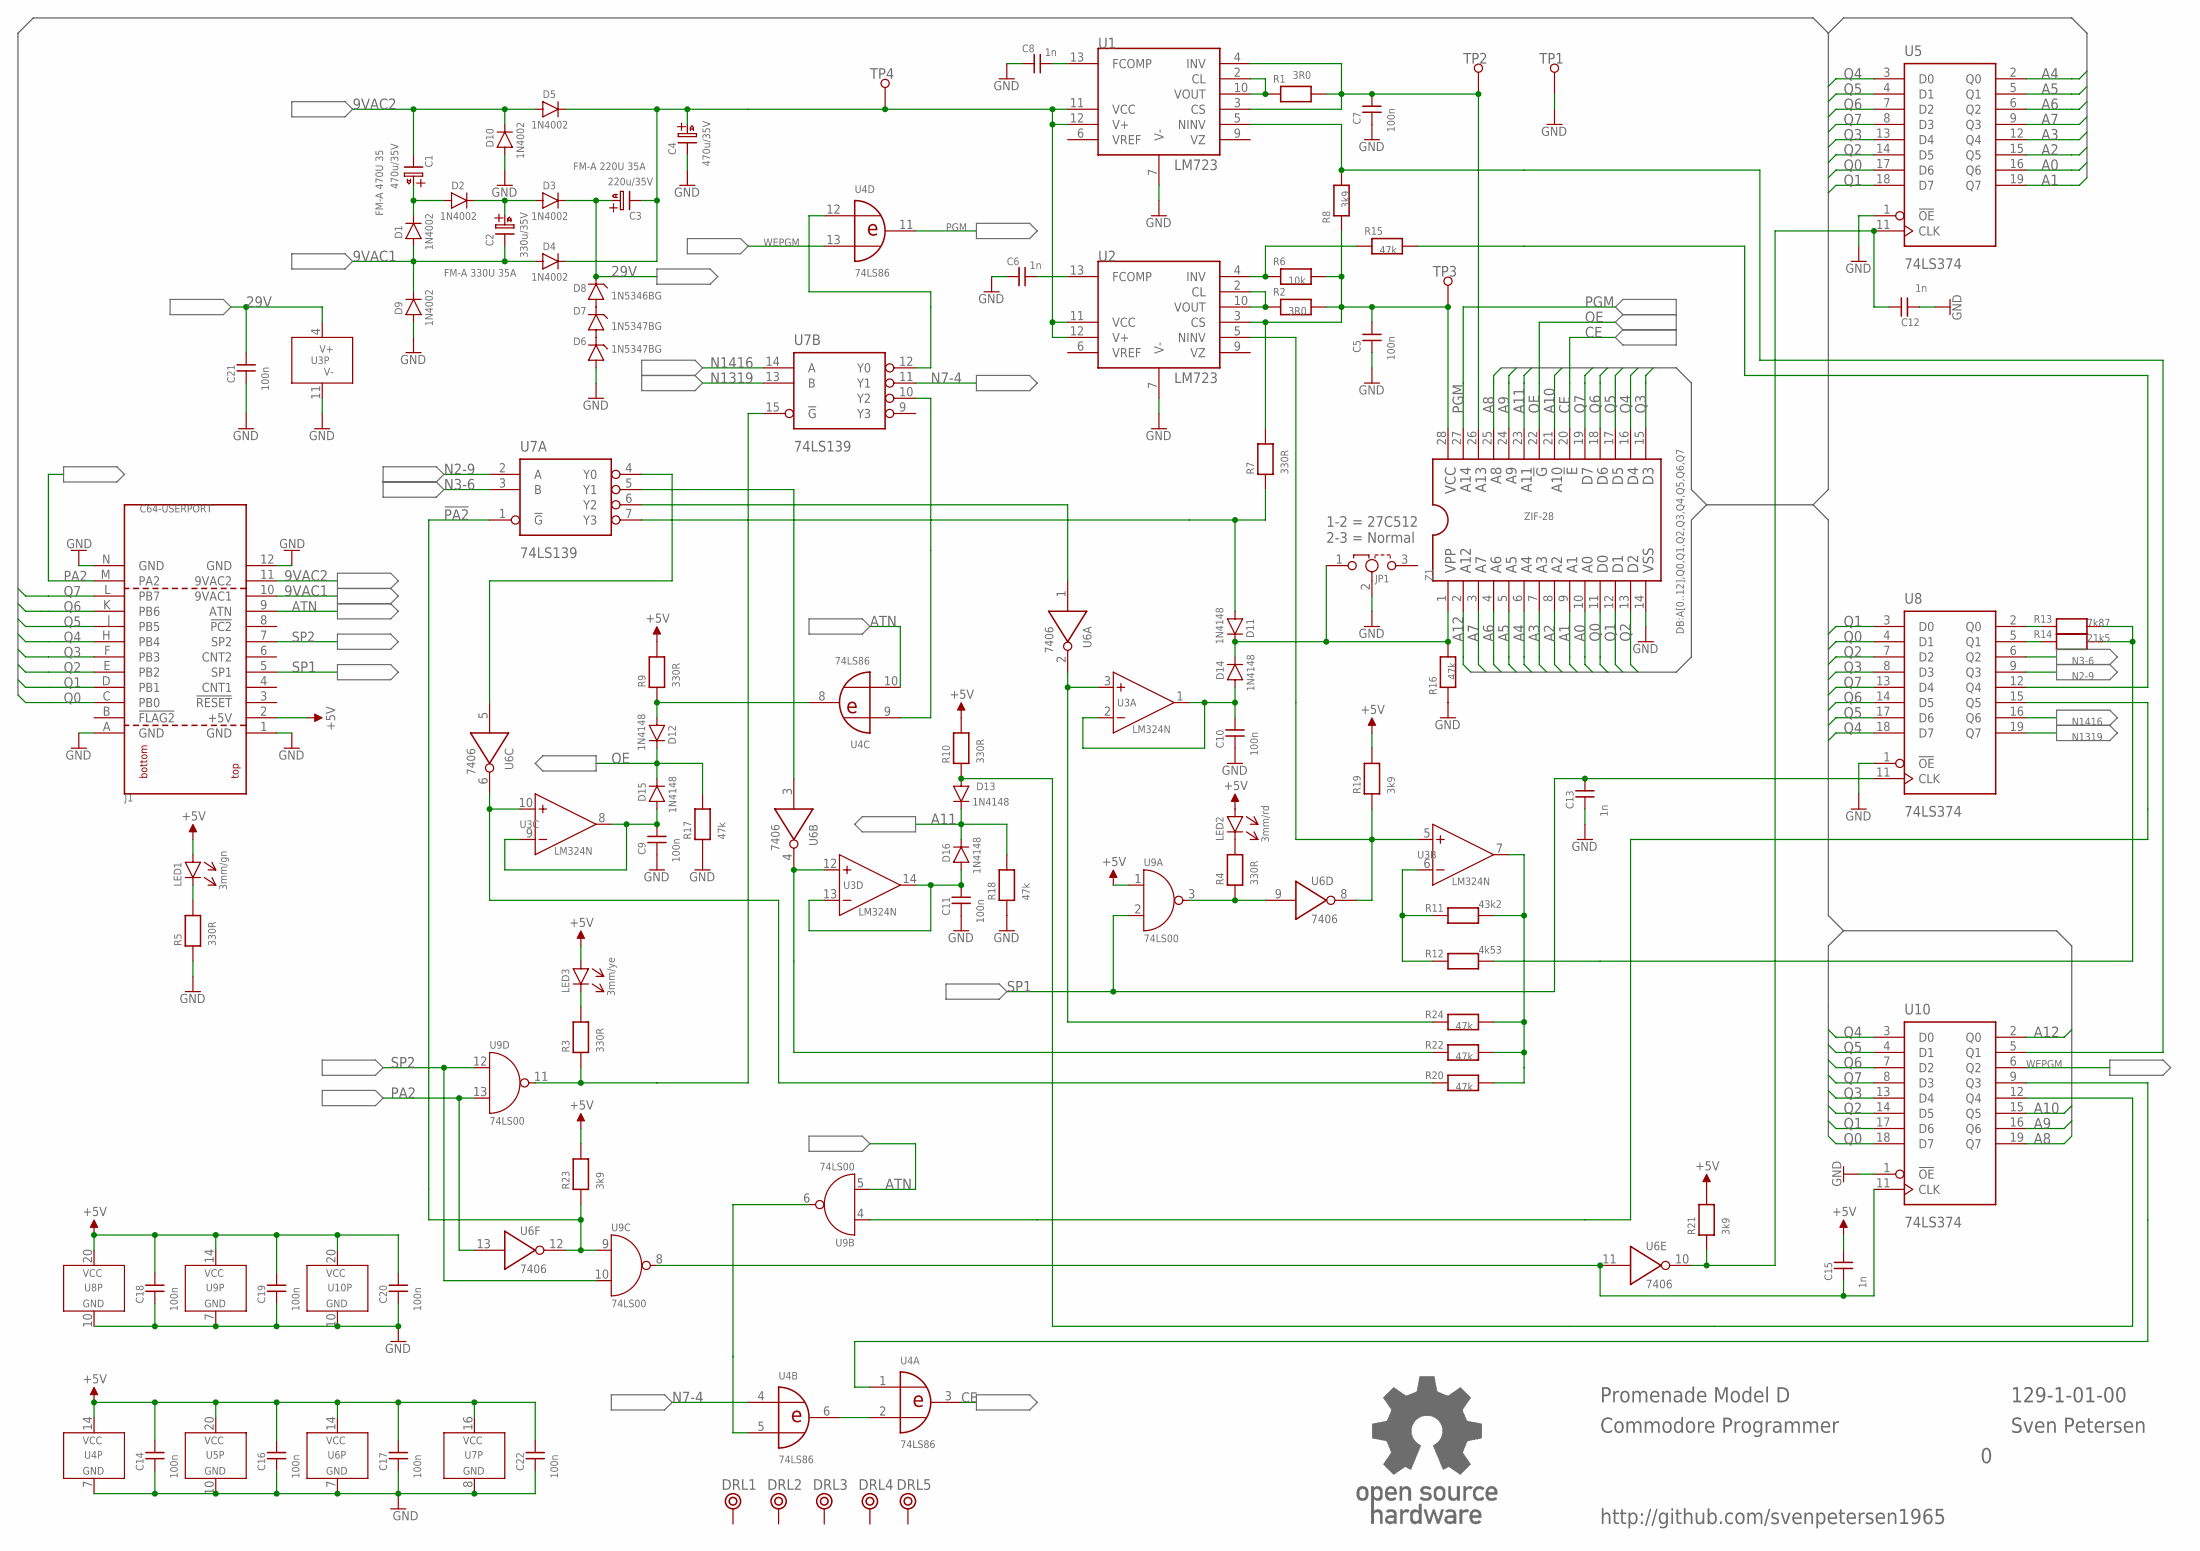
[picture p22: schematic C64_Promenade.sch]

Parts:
C1, C4: 470u/35V; C10/5,0
C2: 330u/35V; C10/5,0
C3: 220u/35V; C10/5,0
C5, C7, C9, C10, C11, C14, C16, C17, C18, C19, C20, C21, C22: 100n; C-2,5
C6, C8, C12, C13, C15: 1n; C-2,5
D1, D2, D3, D4, D5, D9, D10: 1N4002; DO-41
D6, D7: 1N5347BG; 017AA
D8: 1N5346BG; 017AA
D11, D12, D13, D14, D15, D16: 1N4148; DO-35
DRL1, DRL2, DRL3, DRL4, DRL5: BOHR3,5
J1: C64-USERPORT; USERPORT
JP1: DJUMPER; 1X03
LED1: 3mm/gn; 3MM
LED2: 3mm/rd; 3MM
LED3: 3mm/ye; 3MM
R1, R2: 3R0; R-10
R3, R4, R5, R7, R9, R10: 330R; R-10
R6: 10k; R-10
R8, R19, R21, R23: 3k9; R-10
R11: 43k2; R-10
R12: 4k53; R-10
R13: 7k87; R-10
R14: 21k5; R-10
R15, R16, R17, R18, R20, R22, R24: 47k; R-10
TP1, TP2, TP3, TP4: 1,3/2,0
U1, U2: LM723; DIL-14
U3: LM324N; DIL-14
U4: 74LS86; DIL-14
U5, U8, U10: 74LS374; DIL-20
U6: 7406; DIL-14
U7: 74LS139; DIL-16
U9: 74LS00; DIL-14
U$80: OPEN_SOURCE_HW; OPENHW
Z1: ZIF-28; ZIF28

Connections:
9VAC1: C2.-, D1.A, D4.A, D9.K, J1.10 (9VAC1)
9VAC2: C1.-, D5.A, D10.K, J1.11 (9VAC2)
29V: C3.+, C21.2, D3.K, D8.K, U3.4 (V+)
!PA2: R23.1, U6.12 (O), U7.1 (!G), U9.9 (I0)
+5V: C14.2, C15.2, C16.2, C17.2, C18.2, C19.2, C20.2, C22.2, J1.2 (+5V), LED1.A, LED2.A, LED3.A, R9.2, R10.2, R19.2, R21.2, R23.2, U4.14 (VCC), U5.20 (VCC), U6.14 (VCC), U7.16 (VCC), U8.20 (VCC), U9.1 (I0), U9.14 (VCC), U10.20 (VCC)
A0: U5.16 (Q6), Z1.10
A1: U5.19 (Q7), Z1.9
A2: U5.15 (Q5), Z1.8
A3: U5.12 (Q4), Z1.7
A4: U5.2 (Q0), Z1.6
A5: U5.5 (Q1), Z1.5
A6: U5.6 (Q2), Z1.4
A7: U5.9 (Q3), Z1.3
A8: U10.19 (Q7), Z1.25
A9: U10.16 (Q6), Z1.24
A10: U10.15 (Q5), Z1.21
A11: D13.K, D16.K, R18.2, Z1.23
A12: U10.2 (Q0), Z1.2
ATN: J1.9 (ATN), U4.10 (I1), U9.5 (I1)
CE: U4.3 (O), Z1.20
GND: C4.-, C5.1, C6.1, C7.1, C8.1, C9.1, C10.1, C11.1, C12.1, C13.1, C14.1, C16.1, C17.1, C18.1, C19.1, C20.1, C21.1, C22.1, D6.A, D9.A, D10.A, J1.1 (GND), J1.12 (GND), J1.A (GND), J1.N (GND), JP1.2, R5.1, R16.2, R17.1, R18.1, TP1.1, U1.7 (V-), U2.7 (V-), U3.11 (V-), U4.7 (GND), U5.1 (!OE), U5.10 (GND), U6.7 (GND), U7.8 (GND), U8.1 (!OE), U8.10 (GND), U9.7 (GND), U10.1 (!OE), U10.10 (GND), Z1.14
N2-9: U7.2 (A), U8.9 (Q3)
N3-6: U7.3 (B), U8.6 (Q2)
N7-4: U4.4 (I0), U7.11 (Y1)
N1319: U7.13 (B), U8.19 (Q7)
N1416: U7.14 (A), U8.16 (Q6)
unnamed: U6.5 (I), U7.4 (Y0)
unnamed: LED1.C (K), R5.2
unnamed: D7.K, D8.A
unnamed: R3.1, U7.15 (!G), U9.11 (O)
unnamed: LED3.C (K), R3.2
unnamed: U4.2 (I1), U4.6 (O)
unnamed: C9.2, D15.A, U3.8 (O), U3.9 (-)
unnamed: R20.1, U3.10 (+), U6.6 (O)
unnamed: U4.5 (I1), U9.6 (O)
unnamed: D12.A, R9.1, U4.8 (O)
unnamed: U4.9 (I0), U7.10 (Y2)
unnamed: U8.15 (Q5), U9.4 (I0)
unnamed: C11.2, D16.A, U3.13 (-), U3.14 (O)
unnamed: R22.1, U3.12 (+), U6.4 (O)
unnamed: D13.A, R10.1, U10.12 (Q4)
unnamed: D6.K, D7.A
unnamed: U6.3 (I), U7.5 (Y1)
unnamed: C10.2, D14.A, U3.1 (O), U3.2 (-)
unnamed: R24.1, U3.3 (+), U6.2 (O)
unnamed: D11.K, D14.K, JP1.1, R16.1, Z1.1
unnamed: U4.12 (I0), U7.12 (Y0)
unnamed: U6.1 (I), U7.6 (Y2)
unnamed: D11.A, R7.1, U7.7 (Y3)
unnamed: R4.1, U6.9 (I), U9.3 (O)
unnamed: LED2.C (K), R4.2
unnamed: R19.1, U2.5 (NINV), U3.5 (+), U6.8 (O)
unnamed: R11.1, R12.1, U3.6 (-)
unnamed: C15.1, U6.11 (I), U9.8 (O), U10.11 (CLK)
unnamed: R11.2, R20.2, R22.2, R24.2, U3.7 (O)
unnamed: C12.2, R21.1, U5.11 (CLK), U6.10 (O)
unnamed: C1.+, D1.K, D2.A
unnamed: C2.+, D2.K, D3.A
unnamed: C8.2, U1.13 (FCOMP)
unnamed: C3.-, C4.+, D4.K, D5.K, TP4.1, U1.11 (VCC), U1.12 (V+), U2.11 (VCC), U2.12 (V+)
unnamed: R1.2, U1.2 (CL), U1.10 (VOUT)
unnamed: C6.2, U2.13 (FCOMP)
unnamed: R2.2, U2.2 (CL), U2.10 (VOUT)
unnamed: C7.2, R1.1, TP2.1, U1.3 (CS), U1.4 (INV), Z1.26
unnamed: R6.2, R15.2, U2.4 (INV)
unnamed: C5.2, R2.1, R6.1, R7.2, R8.2, TP3.1, U2.3 (CS), Z1.28
unnamed: R8.1, U1.5 (NINV), U10.5 (Q1)
unnamed: R15.1, U8.12 (Q4)
unnamed: R14.2, U8.5 (Q1)
unnamed: R13.2, U8.2 (Q0)
unnamed: R12.2, R13.1, R14.1
unnamed: U4.1 (I0), U10.9 (Q3)
OE: D12.K, D15.K, R17.2, Z1.22
PA2: J1.M (PA2), U6.13 (I), U9.13 (I1)
PGM: U4.11 (O), Z1.27
Q0: J1.C (PB0), U5.17 (D6), U8.4 (D1), U10.18 (D7), Z1.11
Q1: J1.D (PB1), U5.18 (D7), U8.3 (D0), U10.17 (D6), Z1.12
Q2: J1.E (PB2), U5.14 (D5), U8.7 (D2), U10.14 (D5), Z1.13
Q3: J1.F (PB3), U5.13 (D4), U8.8 (D3), U10.13 (D4), Z1.15
Q4: J1.H (PB4), U5.3 (D0), U8.18 (D7), U10.3 (D0), Z1.16
Q5: J1.J (PB5), U5.4 (D1), U8.17 (D6), U10.4 (D1), Z1.17
Q6: J1.K (PB6), U5.7 (D2), U8.14 (D5), U10.7 (D2), Z1.18
Q7: J1.L (PB7), U5.8 (D3), U8.13 (D4), U10.8 (D3), Z1.19
SP1: C13.2, J1.5 (SP1), U8.11 (CLK), U9.2 (I1)
SP2: J1.7 (SP2), U9.10 (I1), U9.12 (I0)
WEPGM: U4.13 (I1), U10.6 (Q2)

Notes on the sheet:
Promenade Model D
Commodore Programmer
Sven Petersen
FM-A 470U 35
FM-A 330U 35A
FM-A 220U 35A
1-2 = 27C512 2-3 = Normal
VCC
VPP
A14
A13
A11
A10
VSS
A12
129-1-01-00
http://github.com/svenpetersen1965

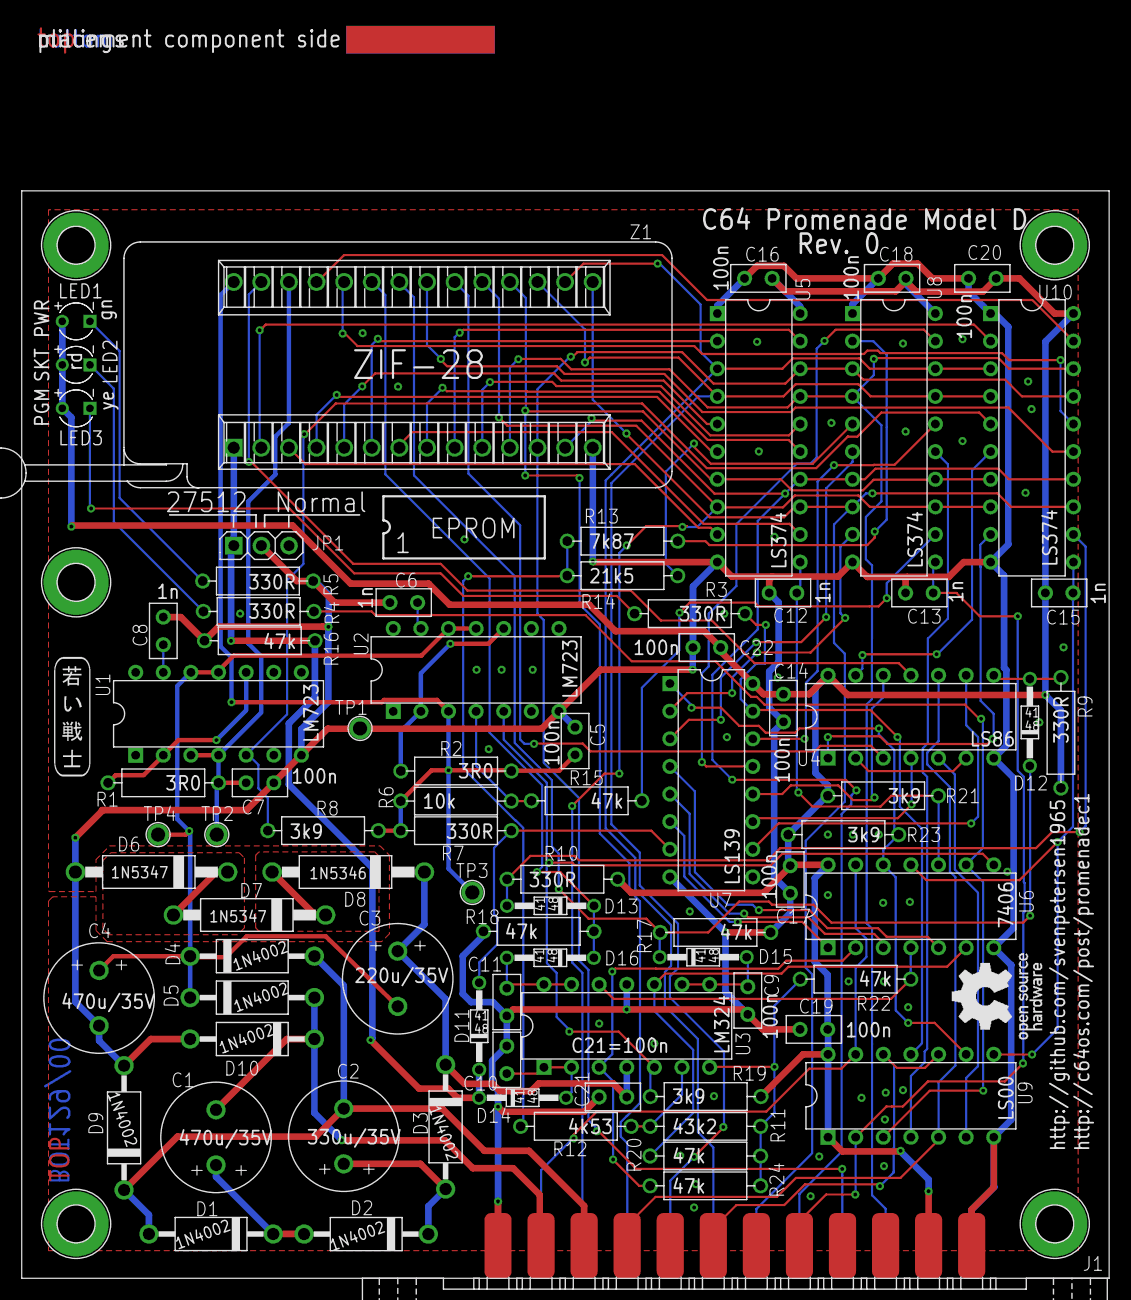
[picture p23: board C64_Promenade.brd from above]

Board: 2 copper layers, 100.0 x 100.0 mm, 91 parts (0 on the bottom side), 86 nets.

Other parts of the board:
U$70: PCB-TITLE/
U$71: 2LAYER
U$81: SVEN_TAG
